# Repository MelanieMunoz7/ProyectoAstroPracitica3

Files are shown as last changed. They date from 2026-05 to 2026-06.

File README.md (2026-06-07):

# **Star Tracker Referencias**

Star Track: 
https://gorkem.cc/projects/StarTrack/

Solar Tracker: 
https://www.instructables.com/Build-a-Dual-Axis-Solar-Tracker-Using-Arduino/

Referencias fotodiodo:
https://www.thorlabs.com/item/FDS100

Refencias Ecuaciones del código Cooper (1996): https://www.sciencedirect.com/science/article/abs/pii/0038092X69900474?via%3Dihub

Master Slave I2C: https://projecthub.arduino.cc/PIYUSH_K_SINGH/master-slave-i2c-connection-31a095

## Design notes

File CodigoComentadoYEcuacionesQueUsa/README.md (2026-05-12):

## **Código Maestro**

En este código el arduino tiene la conexión con el Arduino Esclavo, usando una conexión del tipo RX,TX, con los pines digitales 2 y 3. Además de que esta encargado de realizar todo el análisis, es como el cerebro del sistema. 

Y para comenzar es nesario, definir la latitud de Medellín, la cual se reporta en grados como $6.24°$, por lo que es necesario pasarla a radiones. Luego, la rutina setup, se cersiora de realizar unacomunicación con el serial, el esclavo y el rtc, actualizando el rtc a la hora actual del momento que cuando se carga el código.

Después en la rutina que se repitirá infinitamente (loop): 

* Leer la hora: es necesario extraer primero obtener el día del año, hora, mes, día, minuto y segundo. Para después a través de un conteno de días, sumandolos mes a mes, es decir, enero tiene 31 y febrero tiene 28, sumandolos hacen 59 días. Para después, volver cada día del año un entero, tipo el 15 de marzo, es en enteros $n = 31 + 28 + 15$. Para después reportar la hora, pasando los minutos y segundos a horas, es decir, $14:30:30$ es $14 + 30/60 + 30/3600 = 14.5083$.
* Declinación solar y lunar:
Se presenta la ecuación de Cooper (1969) para calcular la declinación solar $\delta$, la cual se expresa como $\delta =23.45\cdot \sin \left[\frac{360}{365}\cdot (n-81)\cdot \frac{\pi }{180}\right]$ Doonde, $\delta$ (Declinación Solar) es el ángulo resultante expresado en grados que varía entre $+23.45^{\circ }$ (solsticio de verano en el hemisferio norte) y $-23.45^{\circ }$ (solsticio de invierno).Luego $n$ es el día del año o día juliano (1 para el 1 de enero, 365 para el 31 de diciembre). Depués $(n - 81)$, es el desfase temporal, en el cual el día $81$ corresponde al equinoccio de primavera (21 de marzo), momento en el cual la declinación es exactamente 0. Y $\frac{360}{365}$, es el factor que convierte los días transcurridos en grados de arco, asumiendo una órbita circular de 365 días. 
* Ángulo horario: $H = 15  (h - 12)$, donde el $15$ (grados por hora) considera el giro de la Tierra de 360° en 24 horas de la Tierra ($360/24$). Y $h -12$ define el mediodía solar, como el pundo de referencia, es decir, a las $12:00$ $H = 0^{\circ}$.
* Elevación Solar: usando la dey de cosenos para el sistema de coordendas horizontales:  \(\sin (\alpha )=\sin (\phi )\cdot \sin (\delta )+\cos (\phi )\cdot \cos (\delta )\cdot \cos (H)\), donde $\phi$ es la latitud ya mencionada.
* Azimut solar: usando la ecuación \(\cos (A)=\frac{\sin (\delta )-\sin (\alpha )\cdot \sin (\phi )}{\cos (\alpha )\cdot \cos (\phi )}\).

Así, se les da a los servos la posición en elevación y azimut solar, para después leer los resultados de luz capatada por el fotodiodo. E imprimir en el serial, la hora, luz, y la posisicón del servo horizontal y del vertical. Y finalmente enviar al arduino esclavo la posición de los servos. 

## **Código esclavo**

El código del Arduino esclavo se encarga de recibir desde el Arduino maestro las posiciones objetivo para los servomotores y moverlos de manera suave y controlada. Primero establece una comunicación serial usando la librería SoftwareSerial, por donde recibe mensajes con el formato "anguloHorizontal,anguloVertical". Cada mensaje enviado por el maestro contiene los ángulos que deben tomar el servo horizontal y el servo vertical.

En el programa, el esclavo lee carácter por carácter la información recibida hasta encontrar un salto de línea (\n), lo que indica que el mensaje llegó completo. Luego separa los datos usando la coma como referencia y convierte cada valor a enteros para almacenarlos como posiciones objetivo (targetH y targetV).

Después, el código implementa un sistema de suavizado o movimiento incremental. En lugar de mover los servos directamente a la posición final, compara la posición actual del servo con la posición deseada y avanza poco a poco usando pequeños incrementos definidos por la variable stepSize. Esto permite que el movimiento sea más fluido, evita vibraciones bruscas y reduce el esfuerzo mecánico sobre los servomotores.

Finalmente, el Arduino actualiza continuamente las posiciones de ambos servos horizontal y vertical, logrando que la estructura del sistema autoguiado siga la posición calculada por el maestro de forma estable y suave.

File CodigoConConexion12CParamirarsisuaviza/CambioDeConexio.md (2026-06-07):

Para empezar este recableado de forma segura, lo primero que debes hacer es trabajar con ambos Arduinos completamente apagados. Asegúrate de desconectar el cable USB de tu computadora y apagar cualquier batería o fuente externa que le esté dando energía a los servomotores. Una vez que el sistema no tenga nada de corriente, vas a eliminar el problema de raíz desconectando cualquier cable que actualmente una al Arduino Maestro con el Arduino Esclavo. Esto significa que debes quitar por completo los cables que estén en los pines digitales 0 y 1, o en los pines 2 y 3, de modo que ambas placas queden físicamente separadas y sin comunicación entre sí temporalmente.

El siguiente paso es establecer el ancla eléctrica de tu sistema uniendo las tierras de ambas placas. Toma un cable (preferiblemente de color negro para mantener el orden) y conecta un extremo a cualquier pin GND del Arduino Maestro, llevando el otro extremo a un pin GND del Arduino Esclavo. Es vital recordar que si usas una fuente de energía independiente para darle fuerza a los servomotores, el polo negativo de esa fuente también debe estar unido a esta línea de tierra. Sin esta conexión en común, las placas no tendrán un voltaje de referencia y la comunicación fallará.

Ahora vamos a construir la "autopista" de datos utilizando tu protoboard como un distribuidor, dado que tu módulo de reloj RTC también necesita hablar por el bus I2C. Toma un cable desde el pin analógico A4 del Maestro y conéctalo a una fila vacía de la protoboard. Desde esa misma fila exacta, vas a sacar un cable hacia el pin A4 del Esclavo y otro cable hacia el pin SDA de tu reloj. Inmediatamente después, repite esta misma lógica para la línea del pulso de reloj: lleva un cable desde el pin analógico A5 del Maestro hacia una fila nueva en la protoboard, y desde allí reparte un cable hacia el pin A5 del Esclavo y otro hacia el pin SCL del módulo RTC.

Finalmente, haz una revisión visual de los componentes que no debían cambiar. Asegúrate de que el cable de señal de tu fotodiodo siga conectado al pin A0 del Maestro, y que los cables de señal de los servomotores se mantengan en los pines digitales 9 y 10 del Esclavo. Cuando todo esté en su lugar, enciende la fuente de los motores y conecta únicamente el cable USB del Arduino Maestro a tu computadora. De esta manera, tu circuito estará listo: el Esclavo solo recibirá instrucciones por A4 y A5 para mover los motores, dejando el cable USB del Maestro totalmente libre para enviar los datos de irradiancia hacia tu archivo CSV.

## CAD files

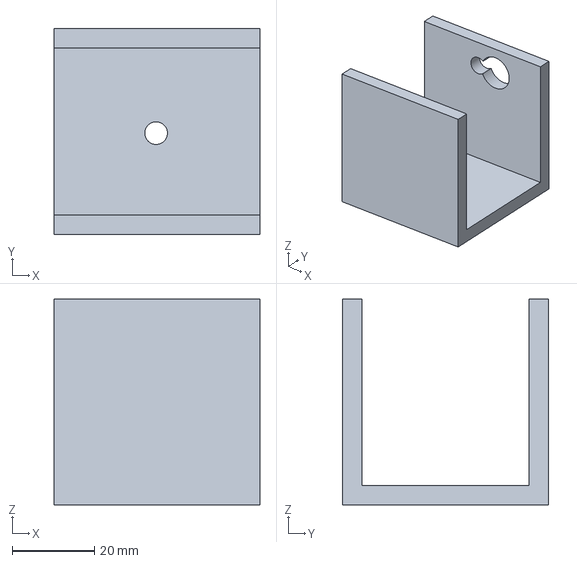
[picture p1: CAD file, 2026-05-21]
Impresiones3d/BaseFull.FCStd
50.0 x 50.0 x 50.0 mm

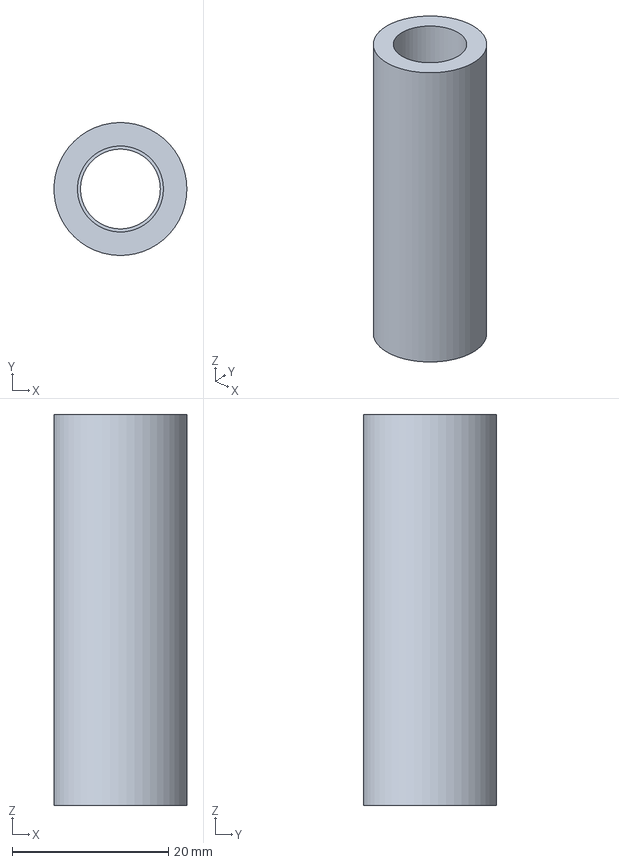
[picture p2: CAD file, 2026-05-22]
Impresiones3d/Tubo_Fotodiodo.FCStd
17.0 x 17.0 x 50.0 mm

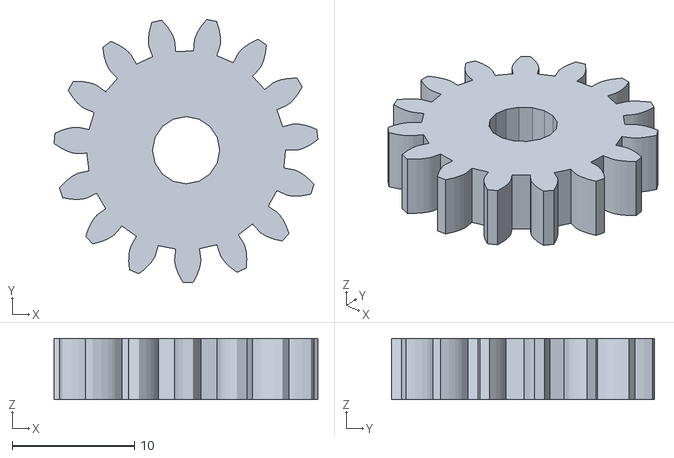
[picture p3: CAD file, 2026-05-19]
Impresiones3d/Engranaje1.stl
21.6 x 21.5 x 5.00

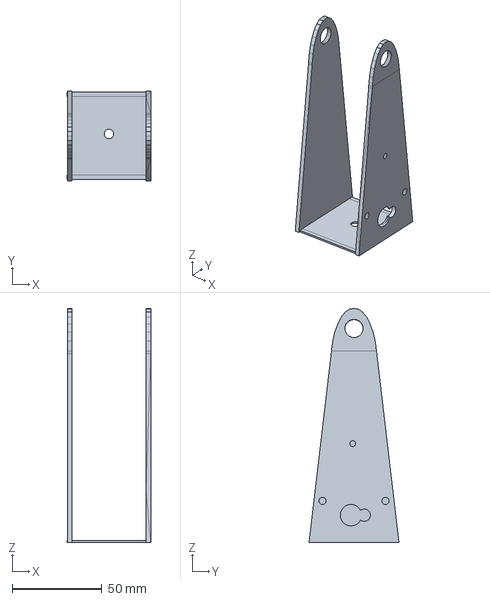
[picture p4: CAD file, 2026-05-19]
Impresiones3d/Base.FCStd
46.4 x 50.0 x 130.0 mm

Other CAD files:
Impresiones3d/Base.stl
Impresiones3d/BaseFull.stl
Impresiones3d/Tubo_Fotodiodo.stl

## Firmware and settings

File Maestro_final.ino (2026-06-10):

#include <SoftwareSerial.h>
#include "RTClib.h"
#include <math.h>

SoftwareSerial puertoEsclavo(2, 3); 

RTC_DS1307 rtc;
int sensor = A0;
float lat = 6.24 * PI / 180; // Latitud de Medellín en radianes

// Función para mapear con precisión decimal
float mapFloat(float x, float in_min, float in_max, float out_min, float out_max)  {
  return (x - in_min) * (out_max - out_min) / (in_max - in_min) + out_min;
}

void setup() {
  Serial.begin(9600);   
  puertoEsclavo.begin(9600);  
  
  if (!rtc.begin()) {
    Serial.println("No se encuentra el RTC");
  }
  
  rtc.adjust(DateTime(F(__DATE__), F(__TIME__))); // Descomentar solo si necesitas resincronizar hora
}

void loop() {
  // -------- 1. LECTURA DEL TIEMPO (RTC) --------
  DateTime now = rtc.now();
  int diasMes[] = {0, 31, 59, 90, 120, 151, 181, 212, 243, 273, 304, 334};
  int n = diasMes[now.month() - 1] + now.day();
  float hourDecimal = now.hour() + now.minute() / 60.0 + now.second() / 3600.0;

  // -------- 2. CÁLCULO ASTRONÓMICO SOLAR (CORREGIDO) --------
  float gamma = (360.0 / 365.0) * (n - 81) * PI / 180.0;
  float delta = 23.45 * PI / 180.0 * sin(gamma); // Declinación en radianes
  float H = 15.0 * (hourDecimal - 12.0) * PI / 180.0; // Ángulo horario en radianes

  // Elevación (Altura)
  float sin_alpha = sin(lat) * sin(delta) + cos(lat) * cos(delta) * cos(H);
  sin_alpha = constrain(sin_alpha, -1.0, 1.0); 
  float alpha = asin(sin_alpha); // Altura en radianes

  // Azimut usando atan2 para evitar errores de cuadrante (Mañana/Tarde)
  float y = -sin(H) * cos(delta);
  float x = sin(lat) * cos(delta) * cos(H) - cos(lat) * sin(delta);
  float A = atan2(y, x); // Azimut en radianes

  // Conversión a grados reales del Sol
  float elev = alpha * 180.0 / PI;
  float azim = A * 180.0 / PI;

  // Ajustar Azimut en rango de 0° a 360°
  if (azim < 0) {
    azim = 360.0 + azim;
  }

  // -------- 3. TRADUCCIÓN A ÁNGULOS DE SERVO --------
  float posH;
  if (azim <= 180) {
    posH = mapFloat(azim, 0.0, 180.0, 90.0, 160.0); 
  } else {
    posH = mapFloat(azim, 180.0, 360.0, 20.0, 90.0);   
  }
  float posV = mapFloat(elev, 0.0, 90.0, 20.0, 160.0);

  // Límites de seguridad física para los servos
  posH = constrain(posH, 20.0, 160.0);
  posV = constrain(posV, 20.0, 160.0);
  
  if (elev < 0) { // Modo nocturno (retorno al origen)
    posH = 90.0; 
    posV = 20.0; 
  }

  // -------- 4. CÁLCULO DE IRRADIANCIA --------
  const float RL = 1000.0;        
  const float RESPONSIVIDAD = 0.54; 
  const float AREA_M2 = 1.37e-5;    
  
  int lectura = analogRead(sensor); 
  float voltaje = (1023.0 - (float)lectura) * (5.0 / 1023.0);
  float corriente = voltaje / RL;
  float potenciaW = corriente / RESPONSIVIDAD;
  float irradiancia = potenciaW / AREA_M2;
  
  // -------- 5. SALIDA AL MONITOR SERIE --------
  Serial.print("Hora: ");
  if(now.hour() < 10) Serial.print('0');
  Serial.print(now.hour()); Serial.print(':');
  if(now.minute() < 10) Serial.print('0');
  Serial.print(now.minute()); Serial.print(':');
  if(now.second() < 10) Serial.print('0');
  Serial.print(now.second());
  
  Serial.print(" | Irradiancia: "); Serial.print(irradiancia, 2); Serial.print(" W/m2");
  Serial.print(" | Azimut Sol: "); Serial.print(azim, 2); Serial.print("°");
  Serial.print(" | Altura Sol: "); Serial.print(elev, 2); Serial.println("°");


  // -------- 6. ENVÍO DE DATOS ENCAPSULADOS AL ESCLAVO --------
  puertoEsclavo.print("<");
  puertoEsclavo.print(posH, 2);
  puertoEsclavo.print(",");
  puertoEsclavo.print(posV, 2);
  puertoEsclavo.println(">");

  delay(20000); 
}

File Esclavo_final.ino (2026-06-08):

#include <SoftwareSerial.h>
#include <Servo.h>

//Configuración de pines para comunicación: RX = 2, TX = 3
SoftwareSerial puertoMaestro(2, 3);

Servo servoH;
Servo servoV;

//Variables de posición con decimales
float targetH = 90.0; 
float targetV = 20.0; 
float currentH = 90.0;
float currentV = 20.0;

//Tamaño del paso para el movimiento lento (0.02 grados)
float stepSize = 0.02; 

//Conversión de alta precisión: Grados flotantes a Microsegundos de pulso
int gradosAMicrosegundos(float grados) {
  return 544 + (grados / 180.0) * (2400 - 544);
}

void setup() {
  puertoMaestro.begin(9600);
  
  servoH.attach(9);
  servoV.attach(10);
  
  //Ubicación inicial suave al arrancar
  servoH.write(90);
  servoV.write(20);
  delay(2000); 
}

void loop() {
  // -------- 1. RECEPCIÓN Y DESEMPAQUETADO DE DATOS --------
  if (puertoMaestro.available() > 0) {
    char inicio = puertoMaestro.read();
    if (inicio == '<') { // Detecta el inicio seguro del mensaje
      targetH = puertoMaestro.parseFloat();
      targetV = puertoMaestro.parseFloat();
    }
  }

  // -------- 2. RAMPA DE SUAVIZADO HORIZONTAL --------
  if (abs(targetH - currentH) > 0.02) {
    if (currentH < targetH) currentH += stepSize;
    else currentH -= stepSize;
    servoH.writeMicroseconds(gradosAMicrosegundos(currentH));
  }

  // -------- 3. RAMPA DE SUAVIZADO VERTICAL --------
  if (abs(targetV - currentV) > 0.02) {
    if (currentV < targetV) currentV += stepSize;
    else currentV -= stepSize;
    servoV.writeMicroseconds(gradosAMicrosegundos(currentV));
  }

  delay(15); // Sincronización del pulso del servo (15ms standard)
}

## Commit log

2026-05-13 Se incluye el calculo de irradiancia del fotodiodo
2026-05-20 Se cambia el sistema para leer coordenadas altazimutales
2026-05-20 movimiento sauviazdo de servos y lectura de coordenadas altazimutales
2026-06-10 codigo usado para la toma de datos
2026-06-10 codigo usado para la toma de datos (esclavo)
